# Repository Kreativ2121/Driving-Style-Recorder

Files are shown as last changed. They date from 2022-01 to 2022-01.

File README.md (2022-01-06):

# Driving Style Recorder
Driving Style Recorded (or DSR, for short) is an Arduino UNO Rev.3 and Nucleo-F303RE based device that will allow users to track the driving history of a vehicle using L76X GPS Module and Sparkfun's CAN-BUS Shield.

## System connections
DSR System

## Data visualisation
Data visualisation app is available at: http://www.cd44289.zut.edu.pl/.
This website is available only through the Intranet of the West Pomeranian University of Technology. You will need VPN connection to access this website.

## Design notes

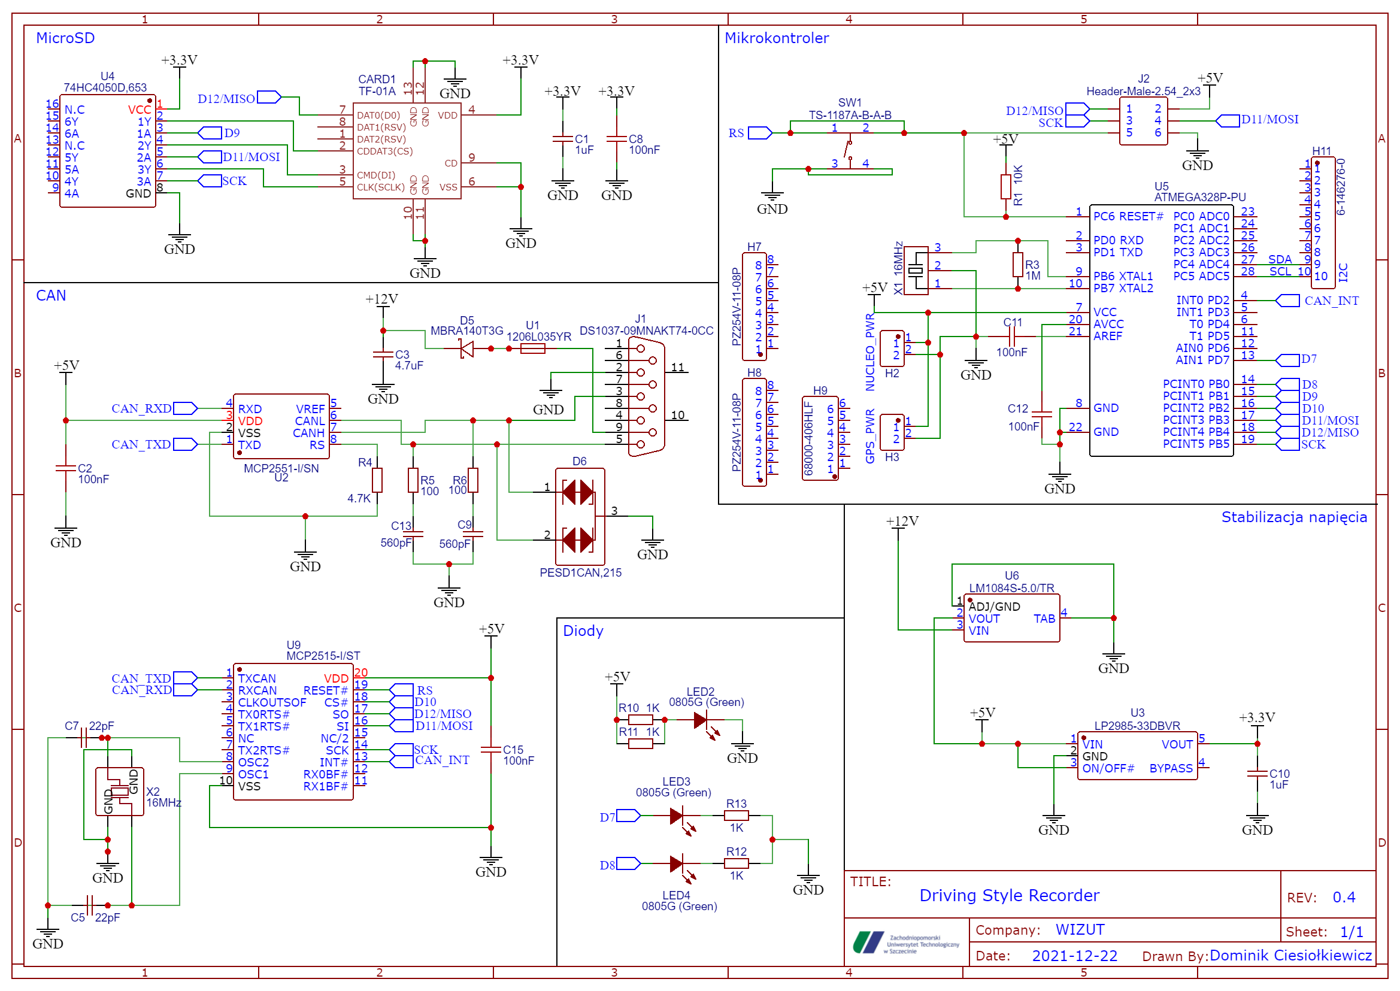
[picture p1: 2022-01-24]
DSR_Board_Project/DSR_Schematic.png

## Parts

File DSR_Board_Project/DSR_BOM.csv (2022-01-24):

ID | Name | Designator | Footprint | Quantity | Manufacturer Part | Manufacturer | Supplier | Supplier Part | Price
1 | 1uF | C1,C10 | C0603 | 2 | CL10A105KB8NNNC | SAMSUNG | LCSC | C15849 | 0.005
2 | 100nF | C2,C8,C11,C12,C15 | C0603 | 5 | CC0603KRX7R9BB104 | YAGEO | LCSC | C14663 | 0.003
3 | 4.7uF | C3 | C0603 | 1 | CL10A475KO8NNNC | SAMSUNG | LCSC | C19666 | 0.011
4 | 22pF | C5,C7 | C0603 | 2 | CL10C220JB8NNNC | SAMSUNG | LCSC | C1653 | 0.005
5 | 560pF | C9,C13 | C0603 | 2 | CL10B561KB8NNNC | SAMSUNG | LCSC | C84721 | 0.006
6 | TF-01A | CARD1 | TF-SMD_TF-01A | 1 | TF-01A | HRO | LCSC | C91145 | 0.183
7 | MBRA140T3G | D5 | SMA_L4.3-W2.6-LS5.2-RD | 1 | MBRA140T3G | ON | LCSC | C54798 | 0.47
8 | PESD1CAN,215 | D6 | SOT-23_L2.9-W1.3-P1.90-LS2.4-BR | 1 | PESD1CAN,215 | Nexperia | LCSC | C15771 | 0.292
9 | 22850102ANG1SYA02 | H2,H3 | HDR-TH_2P-P2.54-V-F | 2 | 22850102ANG1SYA02 | JILN | LCSC | C429966 | 0.037
10 | PZ254V-11-08P | H7,H8 | HDR-TH_8P-P2.54-V-M | 2 | PZ254V-11-08P | XFCN | LCSC | C492407 | 0.05
11 | 68000-406HLF | H9 | HDR-TH_6P-P2.54-V-M-1 | 1 | 68000-406HLF | Amphenol ICC | LCSC | C178289 | 0.387
12 | 6-146276-0 | H11 | CONN-TH_6-146276-0 | 1 | 6-146276-0 | TE Connectivity | LCSC | C306214 | 1.525
13 | DS1037-09MNAKT74-0CC | J1 | DB9-TH_DT10121-M5N3-4F | 1 | DS1037-09MNAKT74-0CC | CONNFLY | LCSC | C75750 | 0.427
14 | Header-Male-2.54_2x3 | J2 | HDR-TH_6P-P2.54-V-M-R2-C3-S2.54-1 | 1 | Header-Male-2.54_2x3 | BOOMELE | LCSC | C65114 | 0.032
15 | 0805G (Green) | LED2,LED3,LED4 | LED0805-RD_GREEN | 3 | 0805G (Green) | KENTO | LCSC | C2297
16 | 10K | R1 | R0603 | 1 | RMC060310K1%N | Tyohm | LCSC | C269701 | 0.003
17 | 1M | R3 | R0603 | 1 | 0603WAF1004T5E | UniOhm | LCSC | C22935 | 0.001
18 | 4.7K | R4 | R0603 | 1 | 0603WAF4701T5E | UniOhm | LCSC | C23162 | 0.001
19 | 100 | R5,R6 | R0603 | 2 | 0603WAF1000T5E | UniOhm | LCSC | C22775 | 0.001
20 | 1K | R10,R11,R12,R13 | R0603 | 4 | 0603WAF1001T5E | UniOhm | LCSC | C21190 | 0.001
21 | TS-1187A-B-A-B | SW1 | SW-SMD_4P-L5.1-W5.1-P3.70-LS6.5-TL-2 | 1 | TS-1187A-B-A-B | XKB Enterprise | LCSC | C318884 | 0.016
22 | 1206L035YR | U1 | F1206 | 1 | 1206L035YR | Littelfuse | LCSC | C99562 | 0.048
23 | MCP2551-I/SN | U2 | SOIC-8_L4.9-W3.9-P1.27-LS6.0-BL | 1 | MCP2551-I/SN | MICROCHIP | LCSC | C7376 | 1.111
24 | LP2985-33DBVR | U3 | SOT-23-5_L2.9-W1.6-P0.95-LS2.8-TL | 1 | LP2985-33DBVR | TI | LCSC | C95414 | 0.327
25 | 74HC4050D,653 | U4 | SOP-16_L10.0-W3.9-P1.27-LS6.0-BL | 1 | 74HC4050D,653 | Nexperia | LCSC | C43181 | 0.33
26 | ATMEGA328P-PU | U5 | DIP-28_L34.6-W7.3-P2.54-LS10.2-BL | 1 | ATMEGA328P-PU | MICROCHIP | LCSC | C33901 | 5.682
27 | LM1084S-5.0/TR | U6 | TO-263-3_L8.6-W10.2-P2.54-LS14.4-TL | 1 | LM1084S-5.0/TR | HGSEMI | LCSC | C259973 | 0.374
28 | MCP2515-I/ST | U9 | TSSOP-20_L6.5-W4.4-P0.65-LS6.4-BL | 1 | MCP2515-I/ST | MICROCHIP | LCSC | C15193 | 3.22
29 | 16MHz | X1 | OSC-SMD_3P-L3.2-W1.3-P0.95-L | 1 | CSTCE16M0V53-R0 | MuRata | LCSC | C32180 | 0.224
30 | 16MHz | X2 | CRYSTAL-SMD_4P-L5.0-W3.2-BL | 1 | K16000J030 | ZheJiang East Crystal Elec | LCSC | C258963 | 0.299

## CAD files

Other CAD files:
Case/DSRCase.f3d

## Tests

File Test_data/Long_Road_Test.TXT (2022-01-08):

0,000.000000,0000.000000,0,0;
0,000.000000,0000.000000,0,0;
0,000.000000,0000.000000,0,0;
0,000.000000,0000.000000,0,0;
0,000.000000,0000.000000,0,0;
0,000.000000,0000.000000,0,0;
0,000.000000,0000.000000,0,0;
0,000.000000,0000.000000,0,0;
0,000.000000,0000.000000,0,0;
0,000.000000,0000.000000,0,0;
0,000.000000,0000.000000,0,0;
0,000.000000,0000.000000,0,0;
0,000.000000,0000.000000,0,0;
0,000.000000,0000.000000,0,0;
0,000.000000,0000.000000,0,0;
0,000.000000,0000.000000,0,0;
0,000.000000,0000.000000,0,0;
0,000.000000,0000.000000,0,0;
0,000.000000,0000.000000,0,0;
0,000.000000,0000.000000,0,0;
0,000.000000,0000.000000,0,0;
0,000.000063,0000.000000,0,0;
0,000.000000,0000.000000,0,0;
0,000.000000,0000.000000,0,0;
0,000.000000,0000.000000,0,0;
0,000.000000,0000.000000,0,0;
0,000.000000,0000.000000,0,0;
1,053.436455,0014.505299,0,0;
1,053.436207,0014.505460,0,0;
1,053.436226,0014.505433,0,0;
1,053.436249,0014.505420,0,0;
1,053.436249,0014.505420,0,0;
1,053.436222,0014.505360,0,0;
1,053.436287,0014.505279,0,0;
1,053.436352,0014.505220,0,0;
1,053.436539,0014.505121,0,0;
1,053.436562,0014.505025,0,0;
1,053.436592,0014.505056,0,0;
1,053.436592,0014.505096,0,0;
1,053.436459,0014.504969,0,0;
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

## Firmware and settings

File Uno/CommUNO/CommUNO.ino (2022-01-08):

#include <Wire.h>
#include <SD.h>
#include "Canbus.h"
#include "defaults.h"
#include "global.h"
#include "mcp2515.h"
#include "mcp2515_defs.h"

#define BYTES 24 //Bytes expected to be received from I2C

int counter; // counter used in some loop functions
byte buff[BYTES]; //buffer for receiving data from I2C
const int chipSelect = 9; //Chip Select pin is tied to pin 9 on the SparkFun CAN-Bus Shield
tCAN message; //CAN message holder
int interval = 1000; //time interval for CANbus data requests
int speed; //newest speed received from CANbus
int rpm; //newest rpm received from CANbus
unsigned long previousMillis = 0; //variable used in millis() timer
//char buffer[456];  //Data will be temporarily stored to this buffer before being written to the file (CAN related)

void eraseBuffer()
{
  //Erasing the I2C buffer
  for(int i=0;i<BYTES;i++){
    buff[i]='\0';
  }
}

void printFromBuffer()
{
  //Printing data from I2C buffer to serial
  for(int i=0;i<BYTES;i++){
    Serial.print((char)buff[i]);
  }
}

void canErrorBlink(int blinkTime)
{
  eraseBuffer();

  //Five short blinks - CAN Bus initialisation error
  for(;;)
  {
    digitalWrite(7, HIGH);
    delay(blinkTime);
    digitalWrite(7, LOW);
    delay(blinkTime);
    digitalWrite(7, HIGH);
    delay(blinkTime);
    digitalWrite(7, LOW);
    delay(blinkTime);
    digitalWrite(7, HIGH);
    delay(blinkTime);
    digitalWrite(7, LOW);
    delay(blinkTime);
    digitalWrite(7, HIGH);
    delay(blinkTime);
    digitalWrite(7, LOW);
    delay(blinkTime);
    digitalWrite(7, HIGH);
    delay(blinkTime);
    digitalWrite(7, LOW);
    Serial.print("\n");
    delay(4000);
  }
  
}

void errorBlink(int blinkTime)
{
  eraseBuffer();

  //Three short blinks - I2C Error
  //Three long blinks - SD Error
  digitalWrite(7, HIGH);
  delay(blinkTime);
  digitalWrite(7, LOW);
  delay(blinkTime);
  digitalWrite(7, HIGH);
  delay(blinkTime);
  digitalWrite(7, LOW);
  delay(blinkTime);
  digitalWrite(7, HIGH);
  delay(blinkTime);
  digitalWrite(7, LOW);
  Serial.print("\n");
  delay(4000);
}

void checkAnswers(){
  if (mcp2515_check_message()) 
  {
    if (mcp2515_get_message(&message)) 
    {
      if(message.id == 0x7E8)  //uncomment when you want to filter
      {
        if(message.data[2] == 0x0C)
        {
          Serial.print(F("RPM"));
          rpm = ((256 * message.data[3]) + message.data[4])/4;
          Serial.print(rpm);
          Serial.print(F(" rpm"));
        }
        else
        {
          Serial.print(F("SPEED"));
          speed = message.data[3];
          Serial.print(message.data[3], DEC);
          Serial.print(F(" km/h"));
        }
        Serial.print(F("\n"));
      }
    }
  }
}

void setup()
{
  delay(1000);
  Serial.begin(9600);
  Serial.println();
  Serial.print(F("-------------------------------------\n"));
  Serial.print(F("Driving Style Recorder (DSR) - Arduino UNO Firmware\n"));
  Serial.print(F("Made by Dominik Ciesiolkiewicz (2022)\n"));
  Serial.print(F("Version 0.0.3\n"));
  Serial.print(F("-------------------------------------\n"));
  Serial.print(F("Beginning system startup.\n"));

  pinMode(7,OUTPUT);//Error LED
  pinMode(8,OUTPUT);//Transmission Acknowledge LED

  Serial.print(F("Initializing CANbus communication.\n"));
  if(Canbus.init(CANSPEED_500))  /* Initialise MCP2515 CAN controller at the specified speed */
  {
    Serial.print(F("CANbus communication initialized correctly.\n")); 
  } 
  else
  {
    Serial.print(F("CANbus communication could not be initialised!\n"));
    canErrorBlink(100);
  }  
  delay(1000); 

  Serial.print(F("Initializing I2C bus as master.\n"));
  Wire.begin();
  //Wire.setTimeout(250); //setTimeout nie może być używany z biblioteką wire.
  Serial.print(F("I2C bus initialization complete.\n")); 

  pinMode(chipSelect, OUTPUT);

  counter = 0;
  Serial.print(F("System startup done.\n"));
  Serial.print(F("-------------------------------------\n"));
}

void loop()
{
  //REQUEST NUCLEO GPS DATA --------------------------------------
  Serial.print("Sending I2C data request...\n");
  int ret = Wire.requestFrom(0x02, BYTES);

  //Checking data sent by slave
  counter = 0;
  while (Wire.available()) {
    char c = Wire.read(); //receive a byte as character
    buff[counter] = c; //add the byte to a buffer
    counter++;
  }

  //Checking if all of the characters in the buffer are null
  counter = 0;
  for(int j=0;j<BYTES;j++){
    if(buff[j] == '\0')
    {
      counter++;      
    }
    else
    {
      break;
    }
  }

  //If yes, send an error
  if(counter == BYTES)
  {
    Serial.print(F("Data was not retrieved from I2C correctly!"));
    counter = 0;
    eraseBuffer(); //erasing the buffer for next usage
    errorBlink(100);//show I2C error
    return;
  }
  //or continue normally
  Serial.print(F("Data received successfully.\n"));
  counter = 0;

  //CAN REQUESTS -------------------------------------------------
  Serial.print(F("Requesting RPM data from CAN...\n"));
  rpm = 0;
  speed = 0;
  unsigned long currentMillis = millis();

  //Sending CAN RPM Request
  Canbus.ecu_req(ENGINE_RPM);

  //Reading RPM
  previousMillis = currentMillis;
  currentMillis = millis();

  while((unsigned long)(currentMillis - previousMillis) < interval) {
    checkAnswers();
    currentMillis = millis();
  }
  previousMillis = currentMillis;

  Serial.print(F("Finished.\nRequesting speed data from CAN...\n"));
  //Sending CAN Speed Request
  Canbus.ecu_req(VEHICLE_SPEED);
  
  //Reading Speed
  previousMillis = currentMillis;
  currentMillis = millis();
  
  while((unsigned long)(currentMillis - previousMillis) < interval) {
    checkAnswers();
    currentMillis = millis();
  }
  previousMillis = currentMillis;
  Serial.print(F("Finished.\n"));

  //SAVING TO SD -------------------------------------------------

  Serial.print(F("Trying to save data on the micro SD card.\n"));

  //Open file on the SD card
  if(!SD.begin(chipSelect)) {
    Serial.println(F("ERROR: Card failed, or not present!"));
    errorBlink(400);
    return;
  }
  File dataFile = SD.open("DSR_GPS.txt", FILE_WRITE);  

  //If the file is available, write to it:
  if (dataFile){
    //Printing data from I2C buffer to serial
    for(int i=0;i<BYTES;i++){
      Serial.print((char)buff[i]);
    }
    Serial.print(",");
    Serial.print(speed);
    Serial.print(",");
    Serial.print(rpm);
    Serial.print(";");
    Serial.println();

    //Save data to SD card
    for(int i=0;i<BYTES;i++){
      dataFile.print((char)buff[i]);
    }
    dataFile.print(",");
    dataFile.print(speed);
    dataFile.print(",");
    dataFile.print(rpm);
    dataFile.print(";");
    dataFile.println();
    
    Serial.print(F("Data saved to SD card successfully.\n"));
    dataFile.close();
  }
  else
  {
    //If the file isn't open, show an error:
    Serial.println(F("Error copying GPS and CAN data to DSRData.txt."));
    dataFile.close();
    errorBlink(400);
        
    return;
  }
  eraseBuffer(); // erasing the buffer for next usage

  //ACKNOWLEDGE --------------------------------------------------
  //Show acknowledge through a fast LED blink
  digitalWrite(8, HIGH);
  delay(200);
  digitalWrite(8, LOW);

  Serial.println();
  delay(4800);
}

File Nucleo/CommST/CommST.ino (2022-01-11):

#include <Wire.h>
#include <SoftwareSerial.h>
#include "DEV_Config.h"
#include "L76X.h"
#include <SPI.h>
#include <SD.h>
GNRMC GPS1;

String LatDmmToDd(double latitude)
{
  String lat;
  String latDec;
  int deg;
  float tempR;
  String temp1, temp2;
  float temp3, temp4;
  
  latDec = String(latitude-(int)latitude,6);
  latDec.remove(0,2);

  deg = (int)latitude;
  temp1 = latDec.substring(0,2);
  temp3 = temp1.toInt();
  temp2 = latDec.substring(2);
  temp4 = temp2.toInt();
  temp4 = temp4/10000.0;
  
  tempR = temp3 + temp4;
  tempR = tempR/60.0;
  lat = String(deg + tempR,6);

  //Serial.println(lat);
  return lat;
}

String LonDmmToDd(double longitude)
{
  String lon;
  String lonDec;
  int deg;
  float tempR;
  String temp1, temp2;
  float temp3, temp4;

  lonDec=String(longitude-(int)longitude,6);
  lonDec.remove(0,2);
  
  deg = (int)longitude;
  temp1 = lonDec.substring(0,2);
  temp3 = temp1.toInt();
  temp2 = lonDec.substring(2);
  temp4 = temp2.toInt();
  temp4 = temp4/10000.0;
  
  tempR = temp3 + temp4;
  tempR = tempR/60.0;
  lon = String(deg + tempR,6);

  //Serial.println(lon);
  return lon;
}

void setup()
{
  delay(1000);
  Serial.begin(9600);
  Serial.println();
  Serial.print(F("-------------------------------------\n"));
  Serial.print(F("Driving Style Recorder (DSR) - Nucleo F303RE Firmware\n"));
  Serial.print(F("Made by Dominik Ciesiolkiewicz (2022)\n"));
  Serial.print(F("Version 0.2.1\n"));
  Serial.print(F("-------------------------------------\n"));
  Serial.print(F("Beginning system startup.\n"));

  pinMode(PA5,OUTPUT);

  Serial.print(F("Beginning GPS initialization.\n"));
  DEV_Set_Baudrate(9600);
  L76X_Send_Command(SET_NMEA_OUTPUT);
  L76X_Send_Command(SET_NMEA_BAUDRATE_9600);
  L76X_Send_Command(SET_POS_FIX_1S);
  L76X_Send_Command(SET_SYNC_PPS_NMEA_OFF);
  L76X_Send_Command(SET_PERIODIC_MODE);
  DEV_Delay_ms(500);
  DEV_Set_Baudrate(9600);
  DEV_Delay_ms(500);
  Serial.print(F("GPS initialization finished.\n"));

  Serial.print(F("Fetching first batch of GPS data...\n"));
  GPS1 = L76X_Gat_GNRMC();
  Serial.print(F("First GPS data fetch complete.\n"));

  Serial.print(F("Initializing I2C bus as slave.\n"));
  Wire.begin(0x02);
  Wire.onRequest(sendMessage);
  Serial.print(F("I2C bus initialization complete.\n"));

  Serial.print(F("System startup done.\n"));
  Serial.print(F("-------------------------------------\n"));
}

void loop()
{
  //Gather data from GPS
  GPS1 = L76X_Gat_GNRMC();
}

void sendMessage()
{
  Serial.println("Request received!");
  
  //Print data to serial
  String Status;
  String Lat;
  String Lon;
  Status.reserve(1);
  Lat.reserve(10);
  Lon.reserve(11);
  Status = String(GPS1.Status);
  Lat = LatDmmToDd(GPS1.Lat);
  Lon = LonDmmToDd(GPS1.Lon);
  
  //Making sure that latitude is exactly 10 bytes long for sending it through I2C
  while(strlen(Lat.c_str())<10)
  {
    if(Lat[0]=='-')
    {
      Lat.remove(1,0);
      Lat = '-' + '0' + Lat;
    }
    else
    {
      Lat = '0' + Lat;
    }
  }

  //Making sure that longitude is exactly 11 bytes long for sending it through I2C
  while(strlen(Lon.c_str())<11)
  {
    if(Lon[0]=='-')
    {
      Lon.remove(1,0);
      Lon = '-' + '0' + Lon;
    }
    else
    {
      Lon = '0' + Lon;
    }
  }

  //Turn on the bulit-in LED to show the user that data is being sent
  digitalWrite(PA5, HIGH);

  //Send data through I2C
  Wire.write(Status.c_str());
  Wire.write(",");
  Wire.write(Lat.c_str());
  Wire.write(",");
  Wire.write(Lon.c_str());

  //Confirm sent data to Serial (DEBUG)
  Serial.print(F("Data sent via I2C to master: "));
  Serial.print(Status);
  Serial.print(",");
  Serial.print(Lat.c_str());
  Serial.print(",");
  Serial.print(Lon.c_str());
  Serial.print("\n");

  //Turn off LED after some time
  delay(200);
  digitalWrite(PA5, LOW);


  //Wire.write("1,53.42399799263681,14.53600240436017700");
}

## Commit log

2022-01-06 Dodano pierwszą wersję oprogramowania na Arduino, Nucleo i stronę WWW do interpretacji wyników.
2022-01-07 DSR PCB Board files have been added.
    [DSR_Altium_Schematic_NOTTESTED.schdoc, DSR_BOM.csv, DSR_PCB_Altium.pcbdoc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]
2022-01-08 Cleaned Arduino UNO file.
2022-01-11 Added 3d case model and fixed a few small bugs.
    [DSRCase.f3d]
2022-01-19 Added some more test data.
    [DSR_Altium_Schematic.schdoc]
2022-01-24 Changed board to have full Arduino pinout for increased stability.
    [DSR_Altium_Schematic.schdoc, DSR_BOM.csv, DSR_PCB_Altium.pcbdoc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]
